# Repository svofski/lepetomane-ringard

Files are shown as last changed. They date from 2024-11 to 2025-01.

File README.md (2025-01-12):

# Pétomane ringard

A "simple" 3-voice "sound chip" with wavetables.

## Current status: 
 - [x] waiting for the first revision of PCB
 - [x] research implementation of USB MIDI
   - [ ] pico firmware in [sw/pico](sw/pico)
 - [x] audio level meter based on CH32V003
    - [CH32V003 specific notes](CH32V003-notes.md)
    - The code for the level meter is [here](wch-ch32v003/pio-arduino-ch32v003)
 - [x] assemble the PCB
   - [x] audio level meter
   - [x] Pi Pico host board
   - [x] main board
 - [ ] verification
   - [x] write a simple serial debug monitor
   - [x] 82c54 can be programmed, produces frequencies as expected
   - [x] counters U10, U11, U12 generate LSB addresses
     - this is hard to verify without a full logic probe (and even with one) but the counting period seems to be correct. I set ctr0 divider = 100, PITCHx256_A is 80kHz; pin U10.9 nRCO has short pulses at 312.5kHz, which is expected because 80e3/256 = 312.5
   - [ ] 82c55
   - [ ] MVOL DAC
   - [ ] WRMODE
   - [ ] LOOPEN_B (one-shot count on channel B)

## About this project

A never ending search of a simple chiptune synthesizer design that could have existed back in the 1980s. This design departs from the tech available to hobbyists in the 80s, but it's not too out there either. 

### Description in broad strokes

The master clock is 8MHz. Potentially 10MHz, but it would be pushing the capabilities of 82C54. The timer divides the main frequency and provides the pitch for the 3 channels. 

Waveforms are stored as samples in a ROM. This is essentially a short sample player. A sample is always 256 counts long, 8-bit waveform. For example, a sawtooth would be a sequence of numbers 0..255 stored in addresses 0..255. 
The ROM has 16 address bits, so there are 256 waveforms. This is how timbre and volume are set: simply by selecting 8 MSB of the sample address. It is possible to define just one waveshape and 256 amplitude levels, or for example 4 waveshapes and 64 amplitude levels for each one. Or several MSB bits could be reserved for selecting drum samples. It's a relatively flexible system.

One important remark. Because this is a frequency divider and the base frequency is only 8MHz, we don't get a good resolution if samples represent a single period. For decent musical resolution the waveforms will have to be squeezed to maybe 32 or 64 samples per period.

The 3 channels are time-multiplexed and sent to the two channels of DAC (TLC7258C) in a sequence. In order to provide a stereo mix, channels A/B/C/A/B/C are steered to channels L/L/R/L/R/R. Hopefully this will create an effect of a stereo mix where Left = A + 0.5B and Right = 0.5 + C.

There is a master volume which is just a second DAC providing reference voltage for the main DAC. If the main DAC is stopped, the master volume can be used to play back samples directly.

Channel B (central) can optionally stop after playing a sample once. This may be useful to play back short drum samples.

The MSB for channels A/B/C is set respectively in the registers A/B/C of 82C55. 

Because ROMs are a rare beast in 2024, K6X4008C1F SRAM is used instead. Only 64K of available address space is used. Loading is facilitated by the same 82C55 chip.

The external interface in the Pétomanesque tradition looks like a parallel port "ПУ" of Vector-06C, but in reality it's just a cursed three-row 2.54mm pin header. It is yet to be discovered whether this could ever be useful in a real computer or not. For now Raspberry Pi Pico will be used as a main driver for this board.

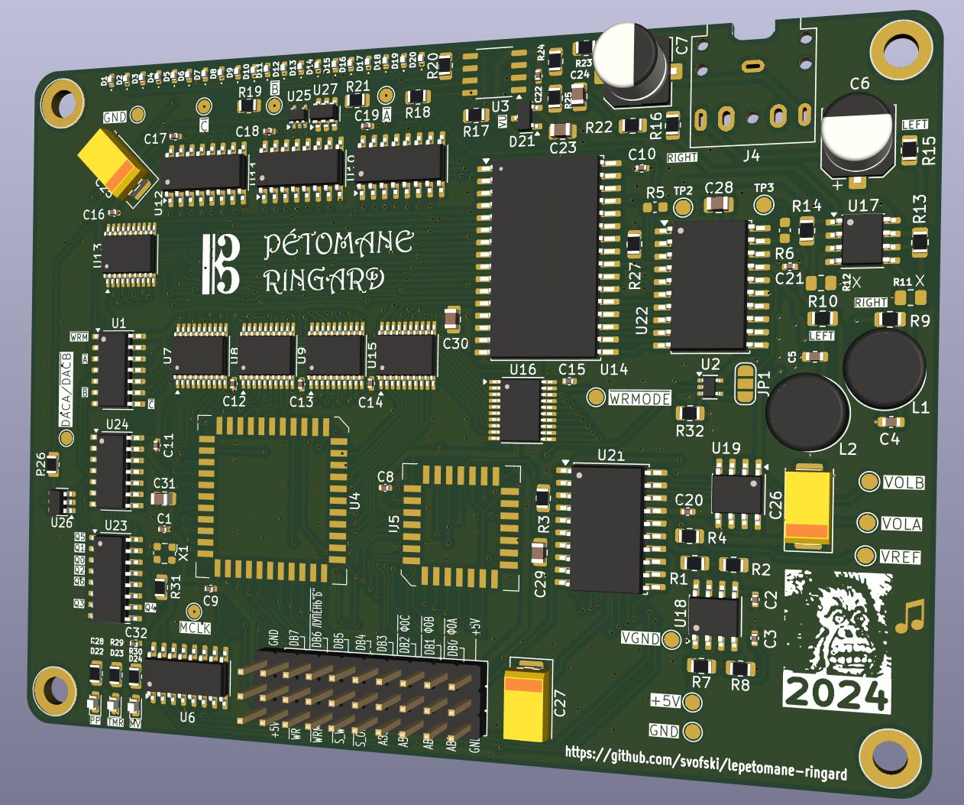
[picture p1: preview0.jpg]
preview


The complexity of this design surpasses the original expecation, yet remains within realm of possibility for a 80s design. SRAM in such quantities would have been wildly expensive back in the day, so a ROM could be used instead.

## Schematic/BOM
 * [https://github.com/svofski/lepetomane-ringard/tree/master/kicad/neopeto](https://kicanvas.org/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)
 * [ibom](https://svofski.github.io/lepetomane-ringard/ibom.html)

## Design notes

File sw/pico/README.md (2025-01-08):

# Raspberry Pi Pico Firmware

Nothing of substance here yet.

# Building

```
mkdir build && cd build && cmake ..
ninja
...
picotool load ringard.bin
```

`picotool reboot -u -f` will not work because reset interface is not implemented, however a 1200 baud hack works. 

On Windows invoke `mode com30 1200` to put pico back into bootloader mode. 

Sometimes USB device would enter some indeterminate state. Use `USBTreeView.exe` to locate the failed hub and invoke `Restart Device` on it.

# Breadcrumbs

### USB / MIDI etc

 * tinymidi example and infovore's [pico-example-midi](https://github.com/infovore/pico-example-midi)
 * Paul Fortescue's [Miscellaneous](https://github.com/PaulFortescue/Miscellaneous)
 * [MIDI as part of a Composite Device #2158](https://github.com/hathach/tinyusb/issues/2158)

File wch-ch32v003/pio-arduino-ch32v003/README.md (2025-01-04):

# Audio level meter based on CH32V003J4M6

This is a simple audio level meter based on a very cheap and compact RISC V based microcontroller. There exist dedicated chips like LM3915, but they are old designs, probably not in production anymore and they are getting harder to find. They also tend to take a lot of board space.

This is a software-defined audio level meter. The circuit is almost as simple as LM3915, but provides more flexibility in terms of functionality as well as PCB layout. The bargraph display proper consists of 20 LEDs. The MCU chip only has 6 pins available for I/O, so the LEDs are charlieplexed.

Charlieplexing is a method of driving a high number of LEDs using few legs. The downside of this method is that multiple LEDs can't be turned on at the same time. In order to display a bar graph, the multiplexing factor is high. In this case 1:20.

video

The LEDs can be grayscaled using PWM. In this application this effect is not practical so the LEDs are on/off only.

The meter is not calibrated to display any specific range of levels, the only thing I aimed for is for it to be entertaining and nice to watch. There are parameters that can be adjusted in the code, such as input gain, integration speed, decay speed and peak holding time. Only integer maths is used.

## Approximate specifications

The numbers, especially refresh rate and sampling rate are approximate just to give the general ballpark figure.

| parameter | value | remark |
| -- | -- | -- |
| supply voltage | 5V or 3.3V |
| number of LEDs | 20 |
| refresh rate | approx. 2.2kHz | 241 cycles / conversion | 
| sampling frequency | 43kHz (estimated) | 241 cycles / conversion |
| refresh rate | approx. 5.1kHz | 73 cycles / conversion |
| sampling frequency | 102kHz (estimated) | 73 cycles / conversion |
| input amplitude | 1V<sub>p-p</sub> |

The ADC is used in continuous sampling mode and the sampling rate is subject to jitter. 

ADC conversion time can be changed in platformio.ini:
```
	-DADC_CYCLES_SEL=7 ; 7: 241 cycles, 6: 73 cycles
```
There is also an artificial delay in the main loop. It has slight effect on perceived brightness and update speeds and can be adjusted to taste. 

## Schematics and layout

This is the complete schematics. There are 3 test pads used for connecting the programmer.
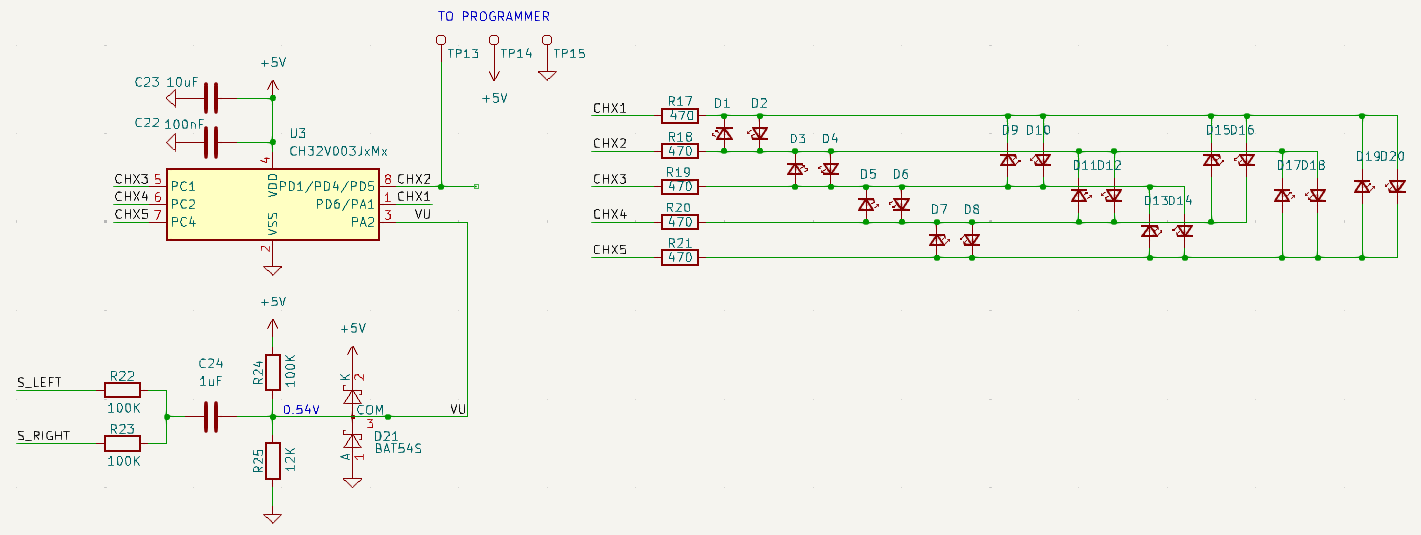
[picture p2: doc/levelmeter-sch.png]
schematics


Example layout on my PCB. Relevant parts are highlighted. The LEDs are 0402.
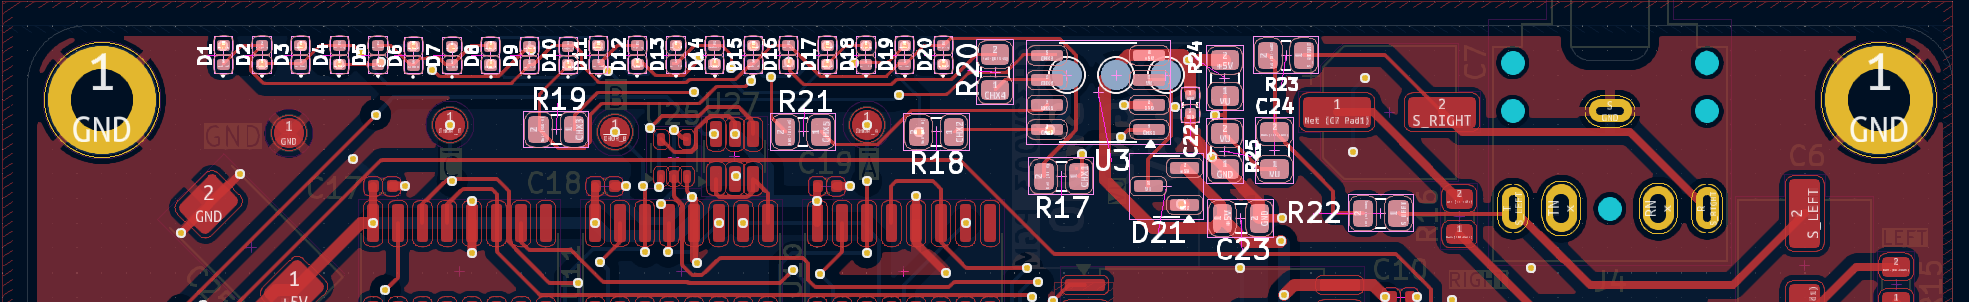
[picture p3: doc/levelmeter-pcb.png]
layout


## Building

The project builds using PlatformIO. See [CH32V003 notes](/CH32V003-notes.md) about setting up the environment.

## Things to improve

 * ADC work is crude.

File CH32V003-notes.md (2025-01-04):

# Notes about using CH32V003J4M6

## Essentials
  
 * Everywhere it's said that only WCH-LinkE will work with this micro. This could be the case in the past, but at the day of writing this (Jan 2025) this is not true. WCH-LinkW also works, even though minichlink.exe might report it as unknown programmer.
 * When the programming pin is also used as GPIO output, it may be impossible to reprogram the micro without removing it from the board.
 * To avoid finding yourself with a bricked MCU, always insert a significant delay in the initialisation code before making GPIO pin PD1/PD4/PD5/SWIO an OUTPUT.
 * It appears that the power provided by the WCH-LinkW dislikes bypass caps on my board. To unbrick a bricked MCU I have to remove it from the board and connect directly to the programmer, then it works.

## Frameworks

Before installing drivers compatible with the Arduino IDE, use the original `WCH-LinkUtility` to switch the programmer into RISCV mode. It ships in ARM mode by default. There are also other ways of switching it, they are documented elsewhere.

### Arduino IDE

The chip can be programmed from the vanilla Arduino IDE thanks to this package: https://github.com/AlexanderMandera/arduino-wch32v003 -- see installation instructions on that page.
minichlink.exe requires WinUSB drivers to be installed using Zadig. This will make WCH Utility not work anymore. You can reinstall the drivers back and forth if you need to use the official utility again.

### PlatformIO

The platform ch32v will not auto-install. It can be installed using this command. This also works on windows.
```
pio pkg install -g -p https://github.com/Community-PIO-CH32V/platform-ch32v.git
```
Check out the repo for examples. There is an Arduino framework, same as the one used in Arduino IDE as well as [CNLohr's ch32v003fun](https://github.com/cnlohr/ch32v003fun).
The main repo for ch32v003fun https://github.com/cnlohr/ch32v003fun

### Floating point

It seems to be that it's enough to specify build_flags in `platformio.ini` like so:
```
build_flags = -lgcc -lm
```
However it results in unresolved reference to `__errno` from `sqrtf` or something else. There is probably a proper way of helping this, but I solved it by defining `int __errno` in the main source file.

### Pinout
ch32v003j4m6 pinout

### References
 * [CH32V003 Datasheet](/doc/CH32V003DS0.PDF)
 * [CH32V003 Reference Manual](/doc/CH32V003RM.PDF)

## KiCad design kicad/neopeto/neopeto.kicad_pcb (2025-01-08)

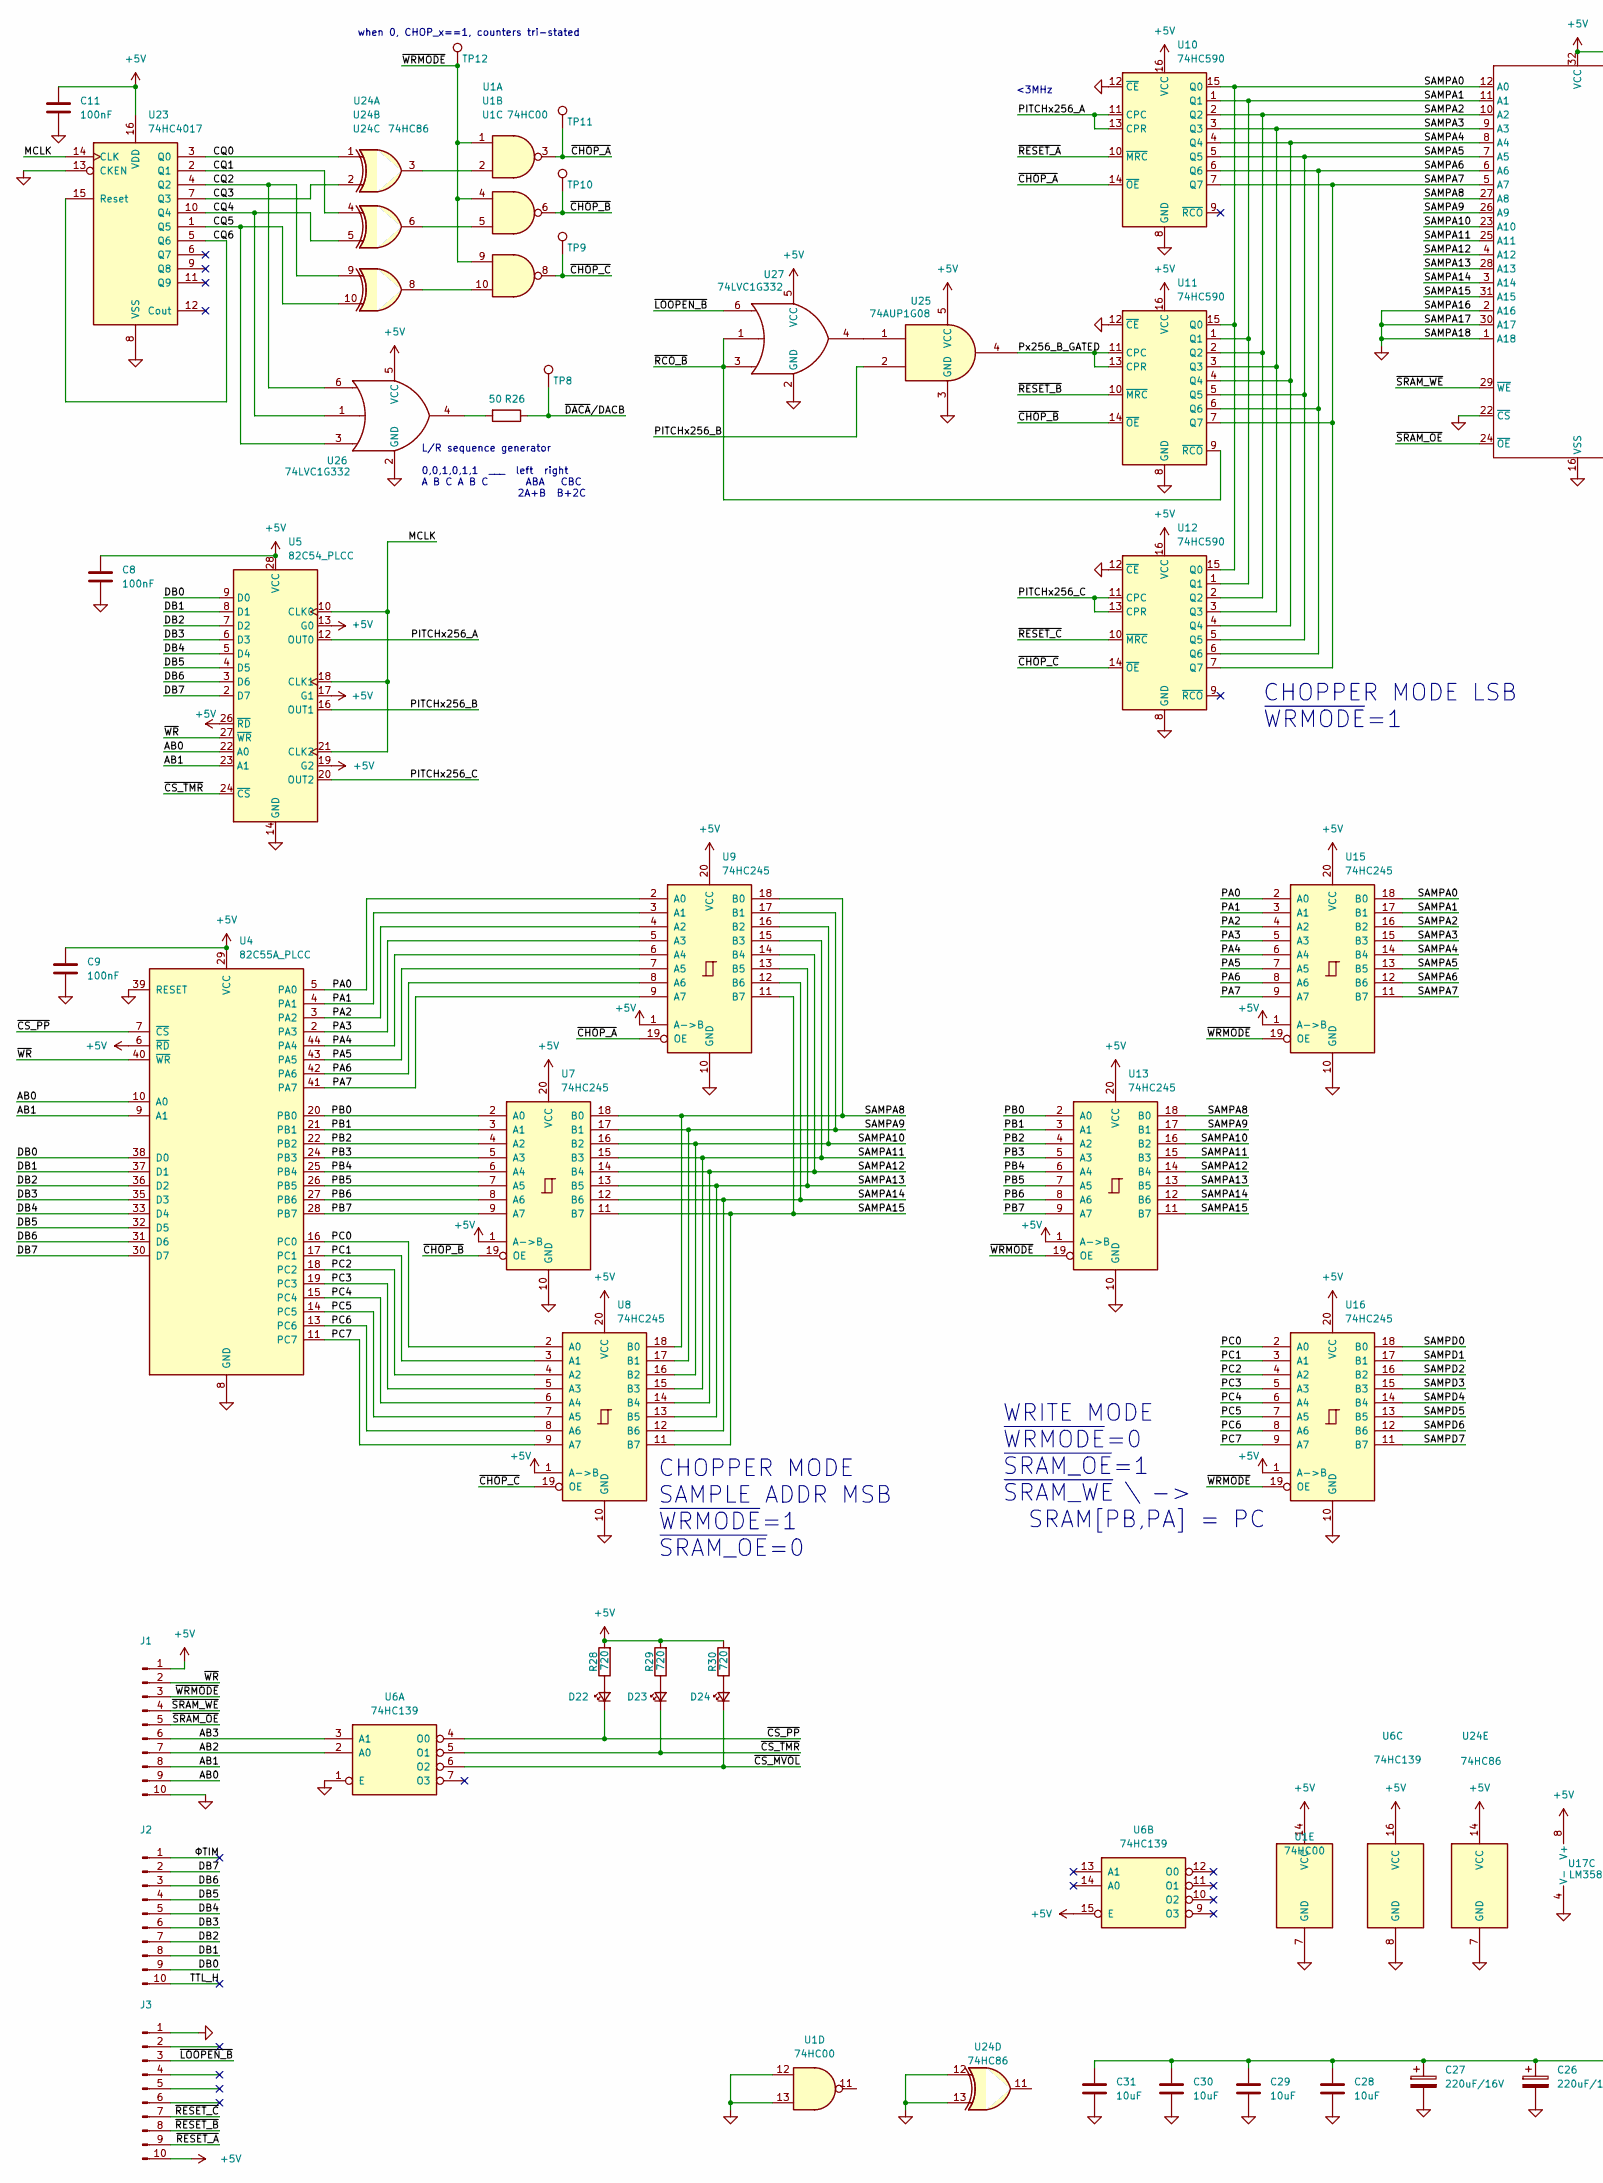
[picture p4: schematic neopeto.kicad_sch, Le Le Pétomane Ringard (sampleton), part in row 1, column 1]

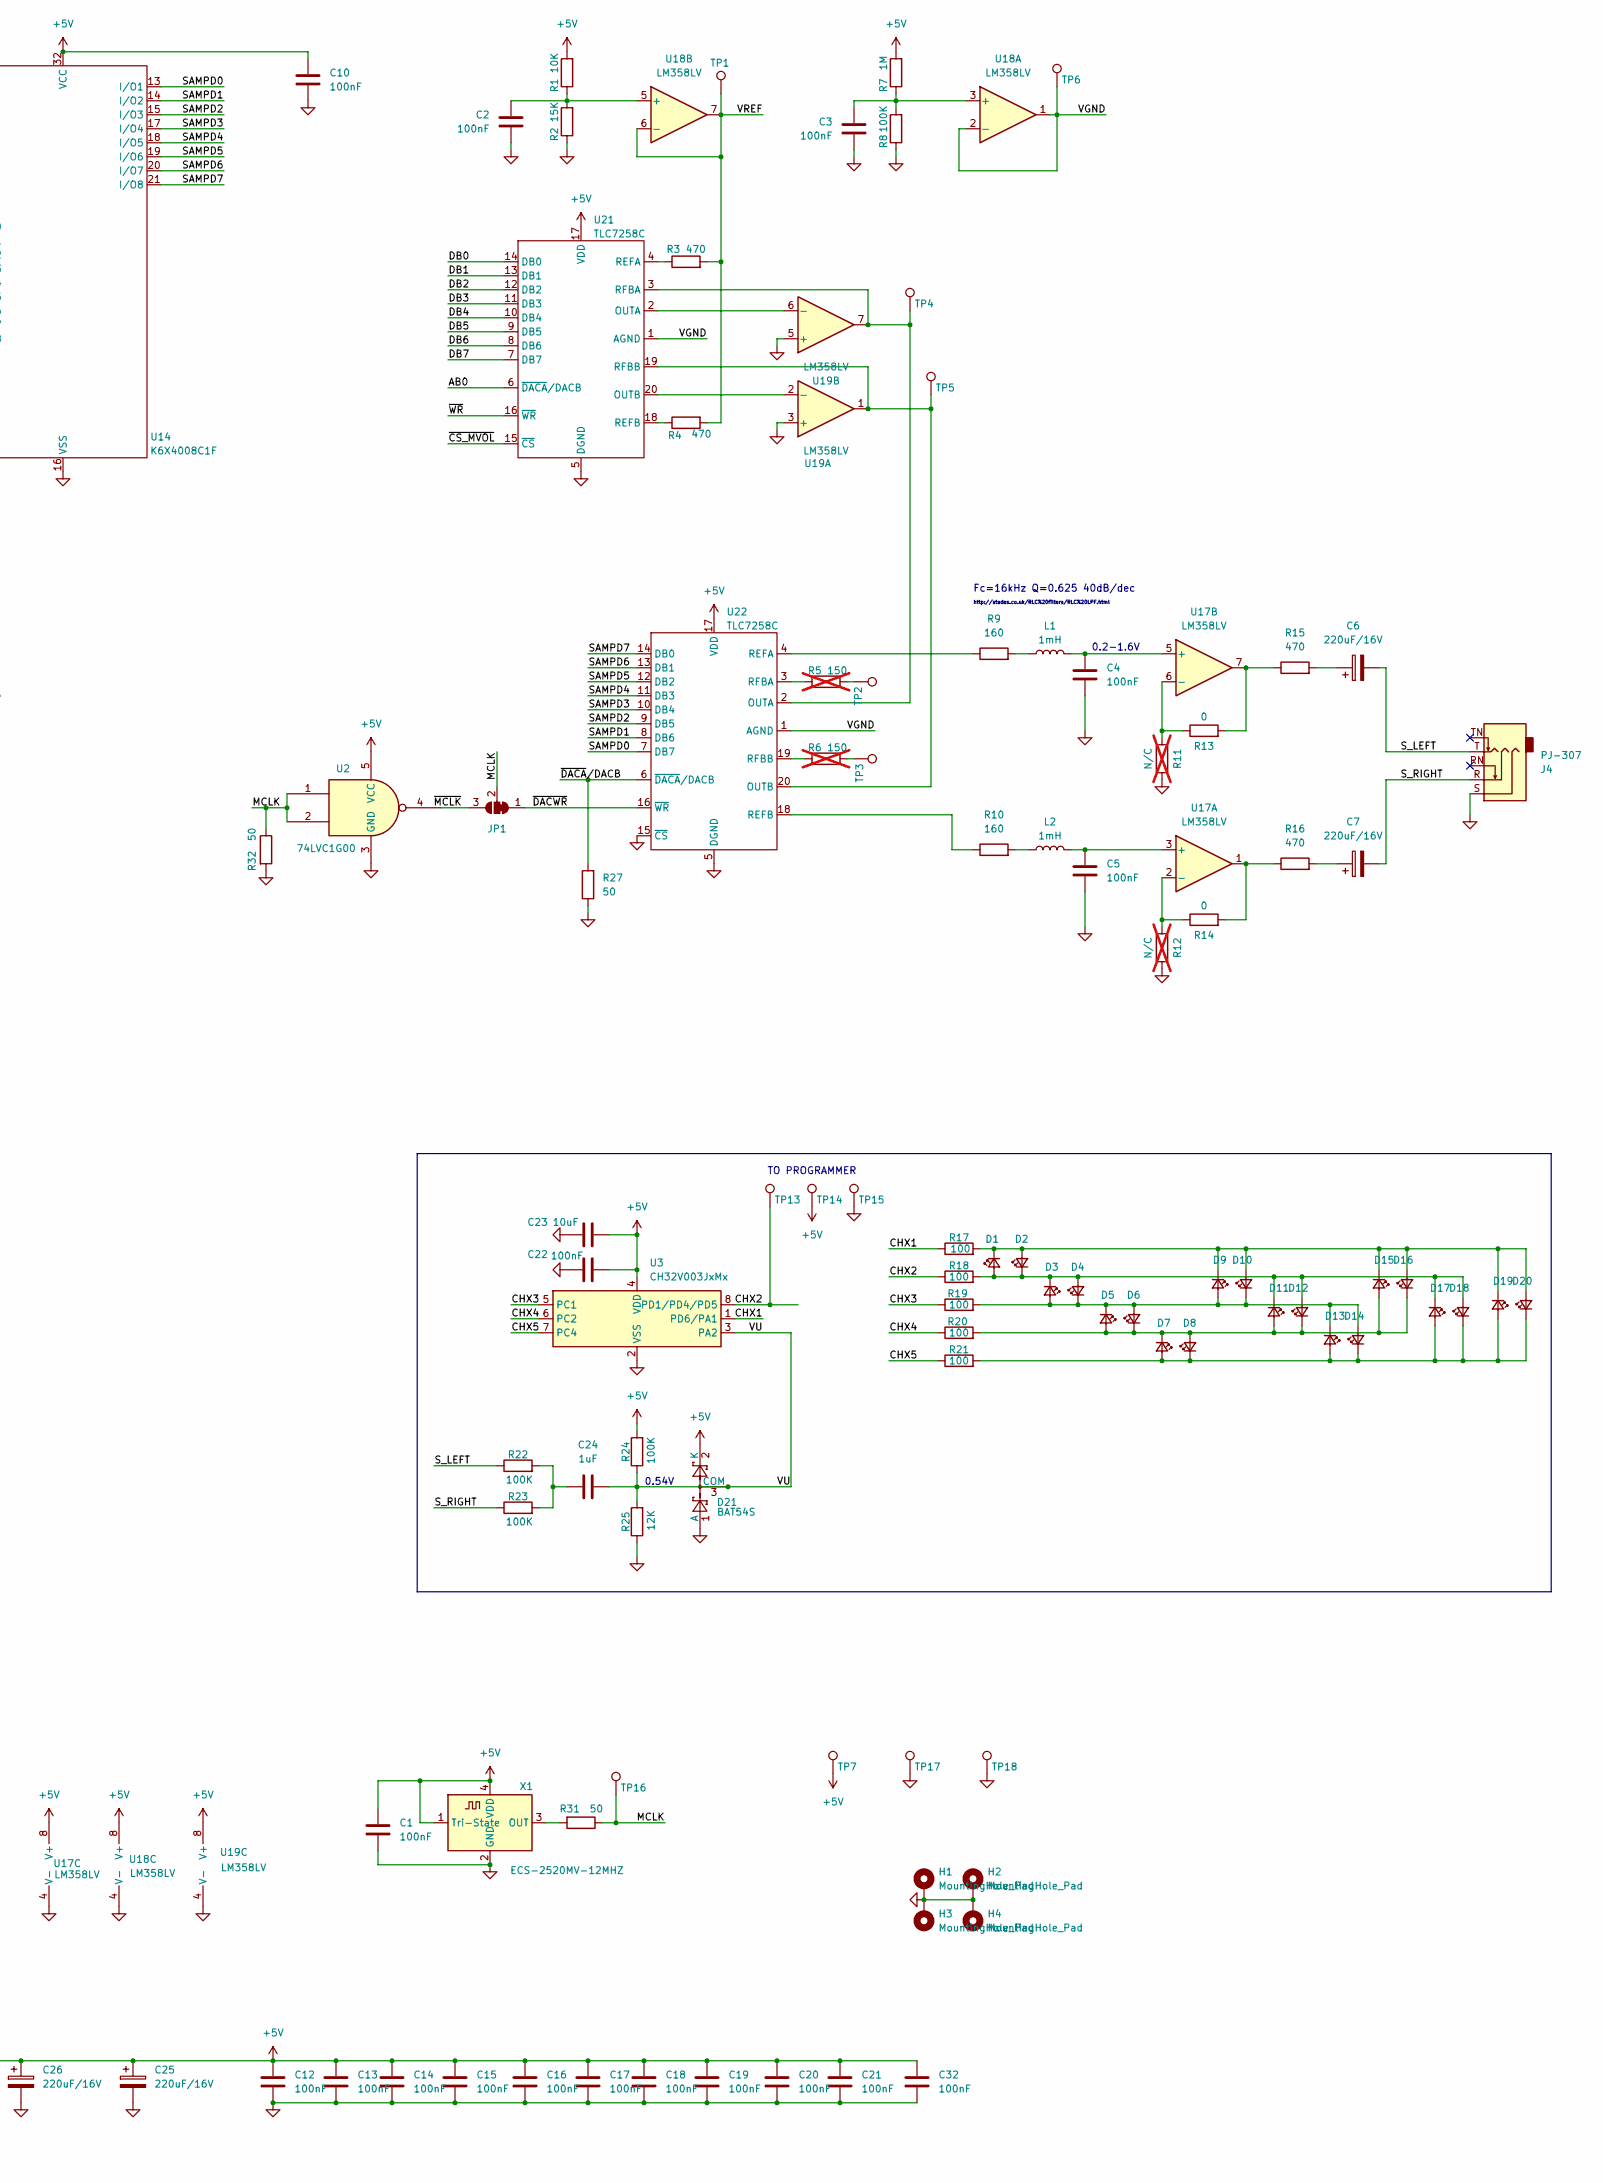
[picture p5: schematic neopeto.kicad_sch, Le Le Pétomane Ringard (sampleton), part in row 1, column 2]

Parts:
C1, C2, C3, C8, C9, C10, C11, C12, C13, C14, C15, C16, C17, C18, C19, C20, C21, C22, C32: 100nF; C_0402_1005Metric
C4, C5: 100nF; C_0603_1608Metric
C6, C7: 220uF/16V; CP_Elec_6.3x7.7
C23, C28, C29, C30, C31: 10uF; C_0805_2012Metric
C24: 1uF; C_0805_2012Metric
C25, C26, C27: 220uF/16V; CP_EIA-7343-31_Kemet-D
D1, D2, D3, D4, D5, D6, D7, D8, D9, D10, D11, D12, D13, D14, D15, D16, D17, D18, D19, D20: LED_Small; LED_0402_1005Metric
D21: BAT54S; SOT-23
D22, D23, D24: LED_Small; LED_0603_1608Metric
H1, H2, H3, H4: MountingHole_Pad; MountingHole_3.2mm_M3_DIN965_Pad
J1, J2, J3: Conn_01x10_Pin; PinHeader_1x10_P2.54mm_Vertical
J4: PJ-307; Jack_3.5mm_CUI_SJ1-3525N_Horizontal
JP1: SolderJumper_3_Bridged12; SolderJumper-3_P1.3mm_Bridged12_RoundedPad1.0x1.5mm_NumberL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
L1, L2: 1mH; L_Radial_D7.2mm_P3.00mm_Murata_1700
R1: 10K; R_0805_2012Metric
R2: 15K; R_0805_2012Metric
R3, R4, R15, R16: 470; R_0805_2012Metric
R5, R6: 150; C_0603_1608Metric; not fitted
R7: 1M; R_0805_2012Metric
R8, R22, R23, R24: 100K; R_0805_2012Metric
R9, R10: 160; R_0805_2012Metric
R11, R12: N/C; R_0805_2012Metric; not fitted
R13, R14: 0; R_0805_2012Metric
R17, R18, R19, R20, R21: 100; R_0805_2012Metric
R25: 12K; R_0805_2012Metric
R26, R27, R31, R32: 50; R_0805_2012Metric
R28, R29, R30: 720; R_0805_2012Metric
TP1, TP2, TP3, TP4, TP5, TP6, TP7, TP8, TP9, TP10, TP11, TP12, TP13, TP14, TP15, TP16, TP17, TP18: TestPoint; TestPoint_Pad_D1.5mm
U1: 74HC00; SO-14_3.9x8.65mm_P1.27mm
U2: 74LVC1G00; SOT-353_SC-70-5
U3: CH32V003JxMx; SOP-8_3.9x4.9mm_P1.27mm
U4: 82C55A_PLCC; PLCC-44
U5: 82C54_PLCC; PLCC-28
U6: 74HC139; SOIC-16_3.9x9.9mm_P1.27mm
U7, U8, U9, U13, U15, U16: 74HC245; TSSOP-20_4.4x6.5mm_P0.65mm
U10, U11, U12: 74HC590; SOIC-16_3.9x9.9mm_P1.27mm
U14: K6X4008C1F; SSOP-32_11.305x20.495mm_P1.27mm
U17, U18, U19: LM358LV; SOIC-8_3.9x4.9mm_P1.27mm
U21, U22: TLC7258C; SOIC-20W_7.5x12.8mm_P1.27mm
U23: 74HC4017; SOIC-16_3.9x9.9mm_P1.27mm
U24: 74HC86; SO-14_3.9x8.65mm_P1.27mm
U25: 74AUP1G08; SOT-353_SC-70-5
U26, U27: 74LVC1G332; SOT-23-6
X1: ECS-2520MV-12MHZ; Oscillator_SMD_ECS_2520MV-xxx-xx-4Pin_2.5x2.0mm

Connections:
+5V: C1.2, C8.2, C9.2, C10.2, C11.2, C12.2, C13.2, C14.2, C15.2, C16.2, C17.2, C18.2, C19.2, C20.2, C21.2, C22.1, C23.1, C25.1, C26.1, C27.1, C28.2, C29.2, C30.2, C31.2, C32.2, D21.2 (K), J1.1, J3.10, R1.2, R7.2, R24.2, R28.2, R29.2, R30.2, TP7.1, TP14.1, U1.14 (VCC), U2.5 (VCC), U3.4 (VDD), U4.6 (~RD), U4.29 (VCC), U5.13 (G0), U5.17 (G1), U5.19 (G2), U5.26 (~RD), U5.28 (VCC), U6.15 (E), U6.16 (VCC), U7.1 (A->B), U7.20 (VCC), U8.1 (A->B), U8.20 (VCC), U9.1 (A->B), U9.20 (VCC), U10.16 (VCC), U11.16 (VCC), U12.16 (VCC), U13.1 (A->B), U13.20 (VCC), U14.32 (VCC), U15.1 (A->B), U15.20 (VCC), U16.1 (A->B), U16.20 (VCC), U17.8 (V+), U18.8 (V+), U19.8 (V+), U21.17 (VDD), U22.17 (VDD), U23.16 (VDD), U24.14 (VCC), U25.5 (VCC), U26.5 (VCC), U27.5 (VCC), X1.1 (Tri-State), X1.4 (VDD)
/AB0: J1.9, U4.10 (A0), U5.22 (A0), U21.6 (~DACA/DACB)
/AB1: J1.8, U4.9 (A1), U5.23 (A1)
/AB2: J1.7, U6.2 (A0)
/AB3: J1.6, U6.3 (A1)
/CHX1: R17.1, U3.1 (PD6/PA1)
/CHX2: R18.1, TP13.1, U3.8 (PD1/PD4/PD5)
/CHX3: R19.1, U3.5 (PC1)
/CHX4: R20.1, U3.6 (PC2)
/CHX5: R21.1, U3.7 (PC4)
/CQ0: U23.3 (Q0), U24.1
/CQ1: U23.2 (Q1), U24.4
/CQ2: U23.4 (Q2), U24.9, U26.6
/CQ3: U23.7 (Q3), U24.2
/CQ4: U23.10 (Q4), U24.5, U26.1
/CQ5: U23.1 (Q5), U24.10, U26.3
/CQ6: U23.5 (Q6), U23.15 (Reset)
/DB0: J2.9, U4.38 (D0), U5.9 (D0), U21.14 (DB0)
/DB1: J2.8, U4.37 (D1), U5.8 (D1), U21.13 (DB1)
/DB2: J2.7, U4.36 (D2), U5.7 (D2), U21.12 (DB2)
/DB3: J2.6, U4.35 (D3), U5.6 (D3), U21.11 (DB3)
/DB4: J2.5, U4.33 (D4), U5.5 (D4), U21.10 (DB4)
/DB5: J2.4, U4.32 (D5), U5.4 (D5), U21.9 (DB5)
/DB6: J2.3, U4.31 (D6), U5.3 (D6), U21.8 (DB6)
/DB7: J2.2, U4.30 (D7), U5.2 (D7), U21.7 (DB7)
/MCLK: JP1.2 (C), R31.1, R32.1, TP16.1, U2.1, U2.2, U5.10 (CLK0), U5.18 (CLK1), U5.21 (CLK2), U23.14 (CLK)
/PA0: U4.5 (PA0), U9.2 (A0), U15.2 (A0)
/PA1: U4.4 (PA1), U9.3 (A1), U15.3 (A1)
/PA2: U4.3 (PA2), U9.4 (A2), U15.4 (A2)
/PA3: U4.2 (PA3), U9.5 (A3), U15.5 (A3)
/PA4: U4.44 (PA4), U9.6 (A4), U15.6 (A4)
/PA5: U4.43 (PA5), U9.7 (A5), U15.7 (A5)
/PA6: U4.42 (PA6), U9.8 (A6), U15.8 (A6)
/PA7: U4.41 (PA7), U9.9 (A7), U15.9 (A7)
/PB0: U4.20 (PB0), U7.2 (A0), U13.2 (A0)
/PB1: U4.21 (PB1), U7.3 (A1), U13.3 (A1)
/PB2: U4.22 (PB2), U7.4 (A2), U13.4 (A2)
/PB3: U4.24 (PB3), U7.5 (A3), U13.5 (A3)
/PB4: U4.25 (PB4), U7.6 (A4), U13.6 (A4)
/PB5: U4.26 (PB5), U7.7 (A5), U13.7 (A5)
/PB6: U4.27 (PB6), U7.8 (A6), U13.8 (A6)
/PB7: U4.28 (PB7), U7.9 (A7), U13.9 (A7)
/PC0: U4.16 (PC0), U8.2 (A0), U16.2 (A0)
/PC1: U4.17 (PC1), U8.3 (A1), U16.3 (A1)
/PC2: U4.18 (PC2), U8.4 (A2), U16.4 (A2)
/PC3: U4.19 (PC3), U8.5 (A3), U16.5 (A3)
/PC4: U4.15 (PC4), U8.6 (A4), U16.6 (A4)
/PC5: U4.14 (PC5), U8.7 (A5), U16.7 (A5)
/PC6: U4.13 (PC6), U8.8 (A6), U16.8 (A6)
/PC7: U4.11 (PC7), U8.9 (A7), U16.9 (A7)
/PITCHx256_A: U5.12 (OUT0), U10.11 (CPC), U10.13 (CPR)
/PITCHx256_B: U5.16 (OUT1), U25.2
/PITCHx256_C: U5.20 (OUT2), U12.11 (CPC), U12.13 (CPR)
/Px256_B_GATED: U11.11 (CPC), U11.13 (CPR), U25.4
/SAMPA0: U10.15 (Q0), U11.15 (Q0), U12.15 (Q0), U14.12 (A0), U15.18 (B0)
/SAMPA1: U10.1 (Q1), U11.1 (Q1), U12.1 (Q1), U14.11 (A1), U15.17 (B1)
/SAMPA2: U10.2 (Q2), U11.2 (Q2), U12.2 (Q2), U14.10 (A2), U15.16 (B2)
/SAMPA3: U10.3 (Q3), U11.3 (Q3), U12.3 (Q3), U14.9 (A3), U15.15 (B3)
/SAMPA4: U10.4 (Q4), U11.4 (Q4), U12.4 (Q4), U14.8 (A4), U15.14 (B4)
/SAMPA5: U10.5 (Q5), U11.5 (Q5), U12.5 (Q5), U14.7 (A5), U15.13 (B5)
/SAMPA6: U10.6 (Q6), U11.6 (Q6), U12.6 (Q6), U14.6 (A6), U15.12 (B6)
/SAMPA7: U10.7 (Q7), U11.7 (Q7), U12.7 (Q7), U14.5 (A7), U15.11 (B7)
/SAMPA8: U7.18 (B0), U8.18 (B0), U9.18 (B0), U13.18 (B0), U14.27 (A8)
/SAMPA9: U7.17 (B1), U8.17 (B1), U9.17 (B1), U13.17 (B1), U14.26 (A9)
/SAMPA10: U7.16 (B2), U8.16 (B2), U9.16 (B2), U13.16 (B2), U14.23 (A10)
/SAMPA11: U7.15 (B3), U8.15 (B3), U9.15 (B3), U13.15 (B3), U14.25 (A11)
/SAMPA12: U7.14 (B4), U8.14 (B4), U9.14 (B4), U13.14 (B4), U14.4 (A12)
/SAMPA13: U7.13 (B5), U8.13 (B5), U9.13 (B5), U13.13 (B5), U14.28 (A13)
/SAMPA14: U7.12 (B6), U8.12 (B6), U9.12 (B6), U13.12 (B6), U14.3 (A14)
/SAMPA15: U7.11 (B7), U8.11 (B7), U9.11 (B7), U13.11 (B7), U14.31 (A15)
/SAMPD0: U14.13 (I/O1), U16.18 (B0), U22.7 (DB7)
/SAMPD1: U14.14 (I/O2), U16.17 (B1), U22.8 (DB6)
/SAMPD2: U14.15 (I/O3), U16.16 (B2), U22.9 (DB5)
/SAMPD3: U14.17 (I/O4), U16.15 (B3), U22.10 (DB4)
/SAMPD4: U14.18 (I/O5), U16.14 (B4), U22.11 (DB3)
/SAMPD5: U14.19 (I/O6), U16.13 (B5), U22.12 (DB2)
/SAMPD6: U14.20 (I/O7), U16.12 (B6), U22.13 (DB1)
/SAMPD7: U14.21 (I/O8), U16.11 (B7), U22.14 (DB0)
/S_LEFT: C6.2, J4.T, R22.1
/S_RIGHT: C7.2, J4.R, R23.1
/TTL_H: J2.10
/VGND: TP6.1, U18.1, U18.2 (-), U21.1 (AGND), U22.1 (AGND)
/VREF: R3.2, R4.2, TP1.1, U18.6 (-), U18.7
/VU: C24.1, D21.3 (COM), R24.1, R25.2, U3.3 (PA2)
/~CHOP_A: TP11.1, U1.3, U9.19 (OE), U10.14 (~OE)
/~CHOP_B: TP10.1, U1.6, U7.19 (OE), U11.14 (~OE)
/~CHOP_C: TP9.1, U1.8, U8.19 (OE), U12.14 (~OE)
/~CS_MVOL: D24.1 (K), U6.6 (O2), U21.15 (~CS)
/~CS_PP: D22.1 (K), U4.7 (~CS), U6.4 (O0)
/~CS_TMR: D23.1 (K), U5.24 (~CS), U6.5 (O1)
/~DACA/DACB: R26.1, R27.2, TP8.1, U22.6 (~DACA/DACB)
/~DACWR: JP1.1 (A), U22.16 (~WR)
/~LOOPEN_B: J3.3, U27.6
/~MCLK: JP1.3 (B), U2.4
/~RCO_B: U11.9 (~RCO), U27.1, U27.3
/~RESET_A: J3.9, U10.10 (~MRC)
/~RESET_B: J3.8, U11.10 (~MRC)
/~RESET_C: J3.7, U12.10 (~MRC)
/~SRAM_OE: J1.5, U14.24 (~OE)
/~SRAM_WE: J1.4, U14.29 (~WE)
/~WRMODE: J1.3, TP12.1, U1.1, U1.4, U1.9, U13.19 (OE), U15.19 (OE), U16.19 (OE)
/~WR: J1.2, U4.40 (~WR), U5.27 (~WR), U21.16 (~WR)
/ФTIM: J2.1
GND: C1.1, C2.1, C3.1, C4.1, C5.1, C8.1, C9.1, C10.1, C11.1, C12.1, C13.1, C14.1, C15.1, C16.1, C17.1, C18.1, C19.1, C20.1, C21.1, C22.2, C23.2, C25.2, C26.2, C27.2, C28.1, C29.1, C30.1, C31.1, C32.1, D21.1 (A), H1.1, H2.1, H3.1, H4.1, J1.10, J3.1, J4.S, R2.1, R8.1, R11.1, R12.1, R25.1, R27.1, R32.2, TP15.1, TP17.1, TP18.1, U1.7 (GND), U1.12, U1.13, U2.3 (GND), U3.2 (VSS), U4.8 (GND), U4.39 (RESET), U5.14 (GND), U6.1 (E), U6.8 (GND), U7.10 (GND), U8.10 (GND), U9.10 (GND), U10.8 (GND), U10.12 (~CE), U11.8 (GND), U11.12 (~CE), U12.8 (GND), U12.12 (~CE), U13.10 (GND), U14.1 (A18), U14.2 (A16), U14.16 (VSS), U14.22 (~CS), U14.30 (A17), U15.10 (GND), U16.10 (GND), U17.4 (V-), U18.4 (V-), U19.3 (+), U19.4 (V-), U19.5 (+), U21.5 (DGND), U22.5 (DGND), U22.15 (~CS), U23.8 (VSS), U23.13 (CKEN), U24.7 (GND), U24.12, U24.13, U25.3 (GND), U26.2 (GND), U27.2 (GND), X1.2 (GND)
unnamed: C6.1, R15.2
unnamed: C7.1, R16.2
unnamed: C24.2, R22.2, R23.2
unnamed: D1.2 (A), D2.1 (K), D3.1 (K), D4.2 (A), D11.1 (K), D12.2 (A), D17.1 (K), D18.2 (A), R18.2
unnamed: D1.1 (K), D2.2 (A), D9.1 (K), D10.2 (A), D15.1 (K), D16.2 (A), D19.1 (K), D20.2 (A), R17.2
unnamed: D3.2 (A), D4.1 (K), D5.1 (K), D6.2 (A), D9.2 (A), D10.1 (K), D13.1 (K), D14.2 (A), R19.2
unnamed: D5.2 (A), D6.1 (K), D7.1 (K), D8.2 (A), D11.2 (A), D12.1 (K), D15.2 (A), D16.1 (K), R20.2
unnamed: D7.2 (A), D8.1 (K), D13.2 (A), D14.1 (K), D17.2 (A), D18.1 (K), D19.2 (A), D20.1 (K), R21.2
unnamed: D22.2 (A), R28.1
unnamed: D23.2 (A), R29.1
unnamed: D24.2 (A), R30.1
unnamed: L1.1, R9.2
unnamed: L2.1, R10.2
unnamed: R5.2, TP2.1
unnamed: R6.2, TP3.1
unnamed: R13.2, R15.1, U17.7
unnamed: R14.2, R16.1, U17.1
unnamed: R26.2, U26.4
unnamed: U1.2, U24.3
unnamed: U1.5, U24.6
unnamed: U1.10, U24.8
unnamed: C5.2, L2.2, U17.3 (+)
unnamed: R12.2, R14.1, U17.2 (-)
unnamed: C4.2, L1.2, U17.5 (+)
unnamed: R11.2, R13.1, U17.6 (-)
unnamed: C3.2, R7.1, R8.2, U18.3 (+)
unnamed: C2.2, R1.1, R2.2, U18.5 (+)
unnamed: U19.2 (-), U21.20 (OUTB)
unnamed: U19.6 (-), U21.2 (OUTA)
unnamed: R3.1, U21.4 (REFA)
unnamed: R4.1, U21.18 (REFB)
unnamed: TP4.1, U19.7, U21.3 (RFBA), U22.2 (OUTA)
unnamed: TP5.1, U19.1, U21.19 (RFBB), U22.20 (OUTB)
unnamed: R9.1, U22.4 (REFA)
unnamed: R10.1, U22.18 (REFB)
unnamed: R5.1, U22.3 (RFBA)
unnamed: R6.1, U22.19 (RFBB)
unnamed: U25.1, U27.4
unnamed: R31.2, X1.3 (OUT)

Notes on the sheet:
CHOPPER MODE SAMPLE ADDR MSB ~{WRMODE}=1 ~{SRAM_OE}=0
http://stades.co.uk/RLC%20filters/RLC%20LPF.html
L/R sequence generator 0,0,1,0,1,1 ___ left right A B C A B C ABA CBC 2A+B B+2C
WRITE MODE ~{WRMODE}=0 ~{SRAM_OE}=1 ~{SRAM_WE} \ -> SRAM[PB,PA] = PC
<3MHz
TO PROGRAMMER
when 0, CHOP_x==1, counters tri-stated
CHOPPER MODE LSB ~{WRMODE}=1
0.2-1.6V
0.54V
Fc=16kHz Q=0.625 40dB/dec

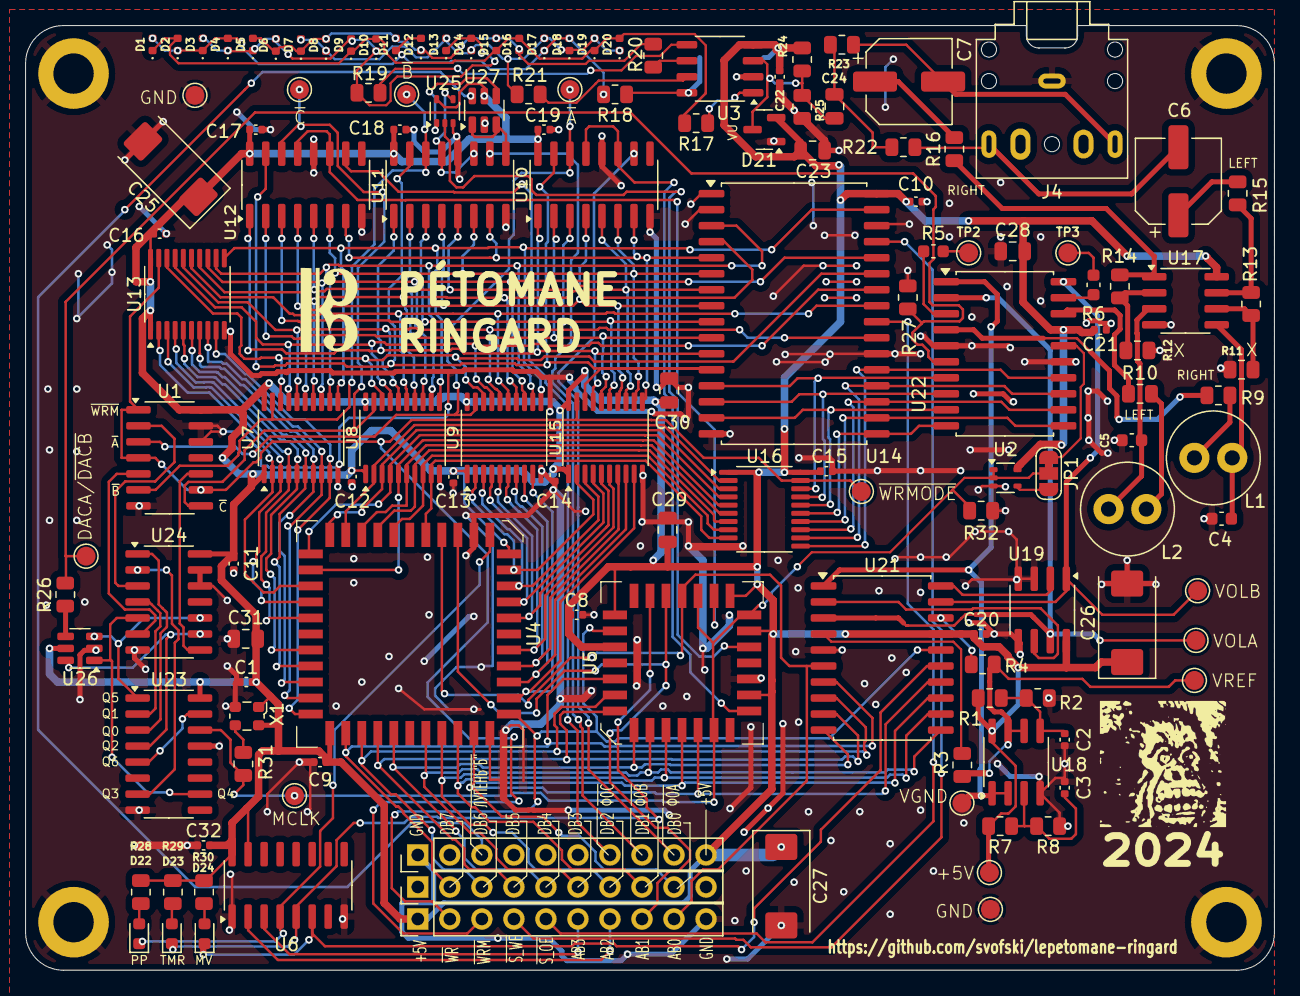
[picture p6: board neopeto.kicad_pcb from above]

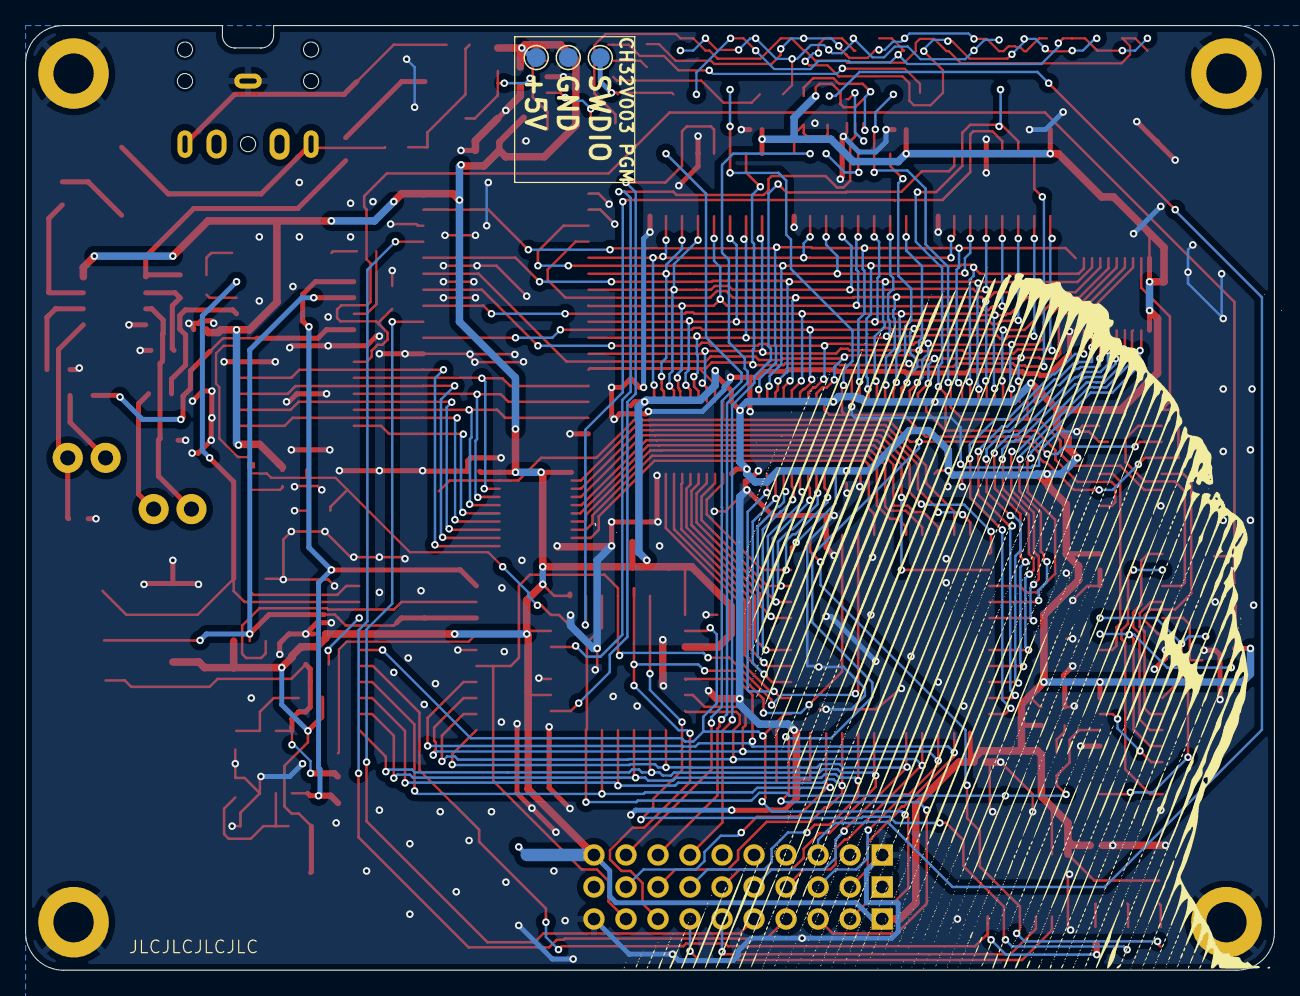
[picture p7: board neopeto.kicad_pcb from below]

Board: 2 copper layers, 99.1 x 74.9 mm, 144 parts (3 on the bottom side), 141 nets.

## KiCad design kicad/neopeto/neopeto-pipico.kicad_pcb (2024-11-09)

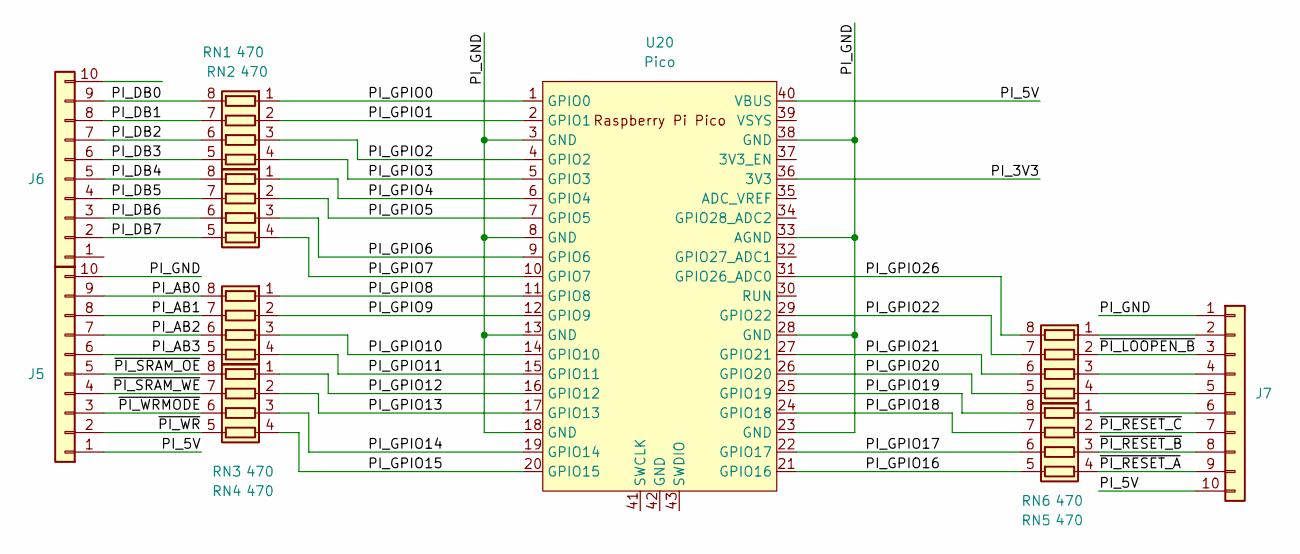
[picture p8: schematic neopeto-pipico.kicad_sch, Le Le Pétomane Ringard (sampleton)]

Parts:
J5, J6, J7: Conn_01x10; PinHeader_1x10_P2.54mm_Vertical
RN1, RN2, RN3, RN4, RN5, RN6: 470; R_Array_Concave_4x0603
U20: Pico; RPi_Pico_SMD_TH

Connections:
/PI_3V3: U20.36 (3V3)
/PI_5V: J5.1, J7.10, U20.40 (VBUS)
/PI_AB0: J5.9, RN3.8 (R1.2)
/PI_AB1: J5.8, RN3.7 (R2.2)
/PI_AB2: J5.7, RN3.6 (R3.2)
/PI_AB3: J5.6, RN3.5 (R4.2)
/PI_DB0: J6.9, RN1.8 (R1.2)
/PI_DB1: J6.8, RN1.7 (R2.2)
/PI_DB2: J6.7, RN1.6 (R3.2)
/PI_DB3: J6.6, RN1.5 (R4.2)
/PI_DB4: J6.5, RN2.8 (R1.2)
/PI_DB5: J6.4, RN2.7 (R2.2)
/PI_DB6: J6.3, RN2.6 (R3.2)
/PI_DB7: J6.2, RN2.5 (R4.2)
/PI_GND: J5.10, J7.1, U20.3 (GND), U20.8 (GND), U20.13 (GND), U20.18 (GND), U20.23 (GND), U20.28 (GND), U20.33 (AGND), U20.38 (GND)
/PI_GPIO0: RN1.1 (R1.1), U20.1 (GPIO0)
/PI_GPIO1: RN1.2 (R2.1), U20.2 (GPIO1)
/PI_GPIO2: RN1.3 (R3.1), U20.4 (GPIO2)
/PI_GPIO3: RN1.4 (R4.1), U20.5 (GPIO3)
/PI_GPIO4: RN2.1 (R1.1), U20.6 (GPIO4)
/PI_GPIO5: RN2.2 (R2.1), U20.7 (GPIO5)
/PI_GPIO6: RN2.3 (R3.1), U20.9 (GPIO6)
/PI_GPIO7: RN2.4 (R4.1), U20.10 (GPIO7)
/PI_GPIO8: RN3.1 (R1.1), U20.11 (GPIO8)
/PI_GPIO9: RN3.2 (R2.1), U20.12 (GPIO9)
/PI_GPIO10: RN3.3 (R3.1), U20.14 (GPIO10)
/PI_GPIO11: RN3.4 (R4.1), U20.15 (GPIO11)
/PI_GPIO12: RN4.1 (R1.1), U20.16 (GPIO12)
/PI_GPIO13: RN4.2 (R2.1), U20.17 (GPIO13)
/PI_GPIO14: RN4.3 (R3.1), U20.19 (GPIO14)
/PI_GPIO15: RN4.4 (R4.1), U20.20 (GPIO15)
/PI_GPIO16: RN5.5 (R4.2), U20.21 (GPIO16)
/PI_GPIO17: RN5.6 (R3.2), U20.22 (GPIO17)
/PI_GPIO18: RN5.7 (R2.2), U20.24 (GPIO18)
/PI_GPIO19: RN5.8 (R1.2), U20.25 (GPIO19)
/PI_GPIO20: RN6.5 (R4.2), U20.26 (GPIO20)
/PI_GPIO21: RN6.6 (R3.2), U20.27 (GPIO21)
/PI_GPIO22: RN6.7 (R2.2), U20.29 (GPIO22)
/PI_GPIO26: RN6.8 (R1.2), U20.31 (GPIO26_ADC0)
/~PI_LOOPEN_B: J7.3, RN6.2 (R2.1)
/~PI_RESET_A: J7.9, RN5.4 (R4.1)
/~PI_RESET_B: J7.8, RN5.3 (R3.1)
/~PI_RESET_C: J7.7, RN5.2 (R2.1)
/~PI_SRAM_OE: J5.5, RN4.8 (R1.2)
/~PI_SRAM_WE: J5.4, RN4.7 (R2.2)
/~PI_WRMODE: J5.3, RN4.6 (R3.2)
/~PI_WR: J5.2, RN4.5 (R4.2)
unnamed: J7.2, RN6.1 (R1.1)
unnamed: J7.4, RN6.3 (R3.1)
unnamed: J7.5, RN6.4 (R4.1)
unnamed: J7.6, RN5.1 (R1.1)

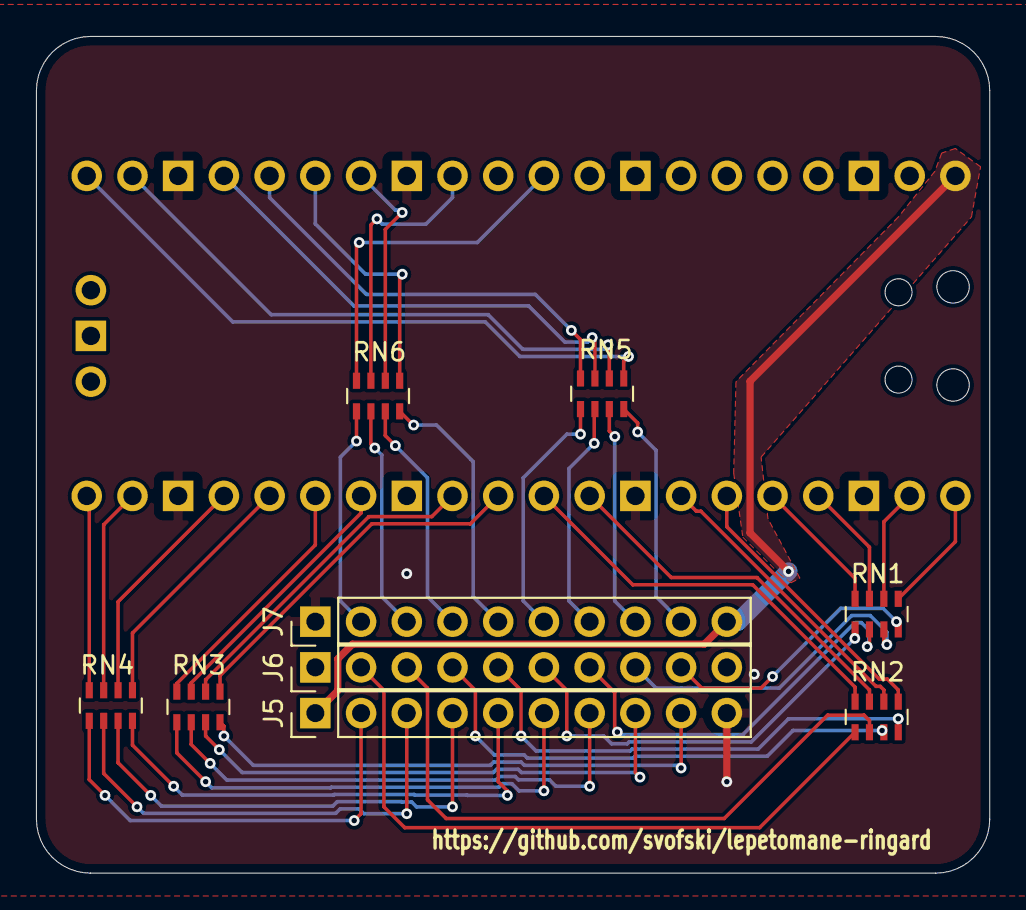
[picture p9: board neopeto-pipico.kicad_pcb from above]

Board: 2 copper layers, 53.0 x 46.5 mm, 10 parts (1 on the bottom side), 50 nets.

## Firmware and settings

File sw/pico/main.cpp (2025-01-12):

#include <array>
#include <cstdlib>

#include <stdio.h>
#include "pico/stdlib.h"
#include "hardware/gpio.h"
#include "pico/binary_info.h"

#include "bsp/board.h"
#include "tusb.h"

#include "petomane.h"

enum  {
    BLINK_NOT_MOUNTED = 250,
    BLINK_MOUNTED = 1000,
    BLINK_SUSPENDED = 2500,
};

Petomane petomane;

static uint32_t blink_interval_ms = BLINK_NOT_MOUNTED;
const uint LED_PIN = PICO_DEFAULT_LED_PIN;

void led_blinking_task(void);
void midi_task(void);

struct DebugMonitor
{
    Petomane& petomane;
    std::array<char, 64> cmdbuf;
    int bufindex;
    int wrn = 0;

    DebugMonitor(Petomane& p): petomane(p), bufindex(0) {}

    void task()
    {
        int c = getchar_timeout_us(10);
        if (c >= 0 && c <= 255) {
            if (c == '\r') {
                c = '\n';
            }
            putchar(c);
            if (c == '\n' || bufindex >= cmdbuf.size() - 1) {
                c = 0;
            }
            cmdbuf[bufindex++] = c;
            if (c == 0) {
                if (bufindex > 1) {
                    process_cmd();
                }
                bufindex = 0;
            }
        }
    }

    void process_cmd()
    {
        int result = 0;
        switch (cmdbuf[0]) {
            case 'd':
                result = process_div();
                break;
            case 'b':
                result = process_bus();
                break;
            case 'w':
                gpio_put(15, wrn);
                wrn ^= 1;
                break;
            default:
                printf("unknown command: [%s]\n", &cmdbuf[0]);
                break;
        }

        if (result == 0) {
            printf("OK\n");
        }
        else {
            printf("ERROR\n");
        }
    }

    void skip_whitespace(int& pos)
    {
        while ((cmdbuf[pos] == ' ' || cmdbuf[pos] == '\t') && pos < cmdbuf.size()) ++pos;
    }

    // d 0 1234 -- sets chan 0 divider to 1234 decimal
    int process_div()
    {
        int pos = 1;

        // first arg
        skip_whitespace(pos);
        if (pos >= cmdbuf.size()) return -1;
        int chan = cmdbuf[pos] - '0';
        if (chan < 0 || chan > 2) return -1;

        // second arg
        ++pos; 
        skip_whitespace(pos);
        if (pos >= cmdbuf.size()) return -1;

        int div = atoi(&cmdbuf[pos]);
        if (div < 0 || div > 65535) return -1;

        printf("set div[%d]=%d\n", chan, div);
        petomane.set_enabled(chan, true);
        petomane.set_div(chan, div);

        return 0;
    }

    // set bus
    // b a b -- abus = a, dbus = b
    // 0-3 = PPI
    // 4-7 = TIMER
    // 8-9 = MVOL
    int process_bus()
    {
        int pos = 1;

        // first arg
        skip_whitespace(pos);
        if (pos >= cmdbuf.size()) return -1;
        int a = cmdbuf[pos] - '0';
        if (a < 0 || a > 9) return -1;

        // second arg
        ++pos; 
        skip_whitespace(pos);
        if (pos >= cmdbuf.size()) return -1;

        uint8_t dbus = atoi(&cmdbuf[pos]) & 0xff;

        int dev = (a & 0xc) >> 2;
        int reg = a & 3;
        printf("set bus dev=%d reg=%d D=%02x\n", dev, reg, dbus);
        petomane.bsr_dev(dev, reg, 0, dbus);

        return 0;
    }
};

DebugMonitor debug_monitor(petomane);

int main() {
    board_init();
    stdio_init_all();
    petomane.board_init();

    tud_init(BOARD_TUD_RHPORT);

    printf("lepetomane-ringard\n");

    while (1)
    {
        tud_task(); // tinyusb device task
        led_blinking_task();
        //midi_task();
        debug_monitor.task();
    }
}

//--------------------------------------------------------------------+
// Device callbacks
//--------------------------------------------------------------------+

// Invoked when device is mounted
void tud_mount_cb(void)
{
    blink_interval_ms = BLINK_MOUNTED;
}

// Invoked when device is unmounted
void tud_umount_cb(void)
{
    blink_interval_ms = BLINK_NOT_MOUNTED;
}

// Invoked when usb bus is suspended
// remote_wakeup_en : if host allow us  to perform remote wakeup
// Within 7ms, device must draw an average of current less than 2.5 mA from bus
void tud_suspend_cb(bool remote_wakeup_en)
{
    (void) remote_wakeup_en;
    blink_interval_ms = BLINK_SUSPENDED;
}

// Invoked when usb bus is resumed
void tud_resume_cb(void)
{
    blink_interval_ms = BLINK_MOUNTED;
}

//--------------------------------------------------------------------+
// MIDI Task
//--------------------------------------------------------------------+

// Variable that holds the current position in the sequence.
uint32_t note_pos = 0;

// Store example melody as an array of note values
uint8_t note_sequence[] =
{
    74,78,81,86,90,93,98,102,57,61,66,69,73,78,81,85,88,92,97,100,97,92,88,85,81,78,
    74,69,66,62,57,62,66,69,74,78,81,86,90,93,97,102,97,93,90,85,81,78,73,68,64,61,
    56,61,64,68,74,78,81,86,90,93,98,102
};

void midi_task(void)
{
    static uint32_t start_ms = 0;
    uint8_t msg[3];

    // send note every 1000 ms
    if (board_millis() - start_ms < 286) return; // not enough time
    start_ms += 286;

    // Previous positions in the note sequence.
    int previous = note_pos - 1;

    // If we currently are at position 0, set the
    // previous position to the last note in the sequence.
    if (previous < 0) previous = sizeof(note_sequence) - 1;

    // Send Note On for current position at full velocity (127) on channel 1.
    msg[0] = 0x90;                    // Note On - Channel 1
    msg[1] = note_sequence[note_pos]; // Note Number
    msg[2] = 127;                     // Velocity
    tud_midi_n_stream_write(0, 0, msg, 3);

    printf("note_on: %02x %02x %02x\n", msg[0], msg[1], msg[2]);

    // Send Note Off for previous note.
    msg[0] = 0x80;                    // Note Off - Channel 1
    msg[1] = note_sequence[previous]; // Note Number
    msg[2] = 0;                       // Velocity
    tud_midi_n_stream_write(0, 0, msg, 3);

    // Increment position
    note_pos++;

    // If we are at the end of the sequence, start over.
    if (note_pos >= sizeof(note_sequence)) note_pos = 0;
}

//--------------------------------------------------------------------+
// BLINKING TASK
//--------------------------------------------------------------------+
void led_blinking_task(void)
{
    static uint32_t start_ms = 0;
    static bool led_state = false;

    // Blink every interval ms
    if ( board_millis() - start_ms < blink_interval_ms) return; // not enough time
    start_ms += blink_interval_ms;

    board_led_write(led_state);
    led_state = 1 - led_state; // toggle
}

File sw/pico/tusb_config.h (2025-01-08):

/*
 * The MIT License (MIT)
 *
 * Copyright (c) 2019 Ha Thach (tinyusb.org)
 *
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
 */

#ifndef _TUSB_CONFIG_H_
#define _TUSB_CONFIG_H_

#ifdef __cplusplus
 extern "C" {
#endif

//--------------------------------------------------------------------+
// Board Specific Configuration
//--------------------------------------------------------------------+

// RHPort number used for device can be defined by board.mk, default to port 0
#ifndef BOARD_TUD_RHPORT
#define BOARD_TUD_RHPORT      0
#endif

// RHPort max operational speed can defined by board.mk
#ifndef BOARD_TUD_MAX_SPEED
#define BOARD_TUD_MAX_SPEED   OPT_MODE_DEFAULT_SPEED
#endif

//--------------------------------------------------------------------
// Common Configuration
//--------------------------------------------------------------------

// defined by compiler flags for flexibility
#ifndef CFG_TUSB_MCU
#error CFG_TUSB_MCU must be defined
#endif

#define CFG_TUSB_RHPORT0_MODE     OPT_MODE_DEVICE

#ifndef CFG_TUSB_OS
#define CFG_TUSB_OS           OPT_OS_NONE
#endif

#ifndef CFG_TUSB_DEBUG
#define CFG_TUSB_DEBUG        0
#endif

// Enable Device stack
#define CFG_TUD_ENABLED       1

// Default is max speed that hardware controller could support with on-chip PHY
#define CFG_TUD_MAX_SPEED     BOARD_TUD_MAX_SPEED

/* USB DMA on some MCUs can only access a specific SRAM region with restriction on alignment.
 * Tinyusb use follows macros to declare transferring memory so that they can be put
 * into those specific section.
 * e.g
 * - CFG_TUSB_MEM SECTION : __attribute__ (( section(".usb_ram") ))
 * - CFG_TUSB_MEM_ALIGN   : __attribute__ ((aligned(4)))
 */
#ifndef CFG_TUSB_MEM_SECTION
#define CFG_TUSB_MEM_SECTION
#endif

#ifndef CFG_TUSB_MEM_ALIGN
#define CFG_TUSB_MEM_ALIGN    __attribute__ ((aligned(4)))
#endif

//--------------------------------------------------------------------
// DEVICE CONFIGURATION
//--------------------------------------------------------------------

#ifndef CFG_TUD_ENDPOINT0_SIZE
#define CFG_TUD_ENDPOINT0_SIZE    64
#endif

//------------- CLASS -------------//
#define CFG_TUD_CDC              1
#define CFG_TUD_MSC              0
#define CFG_TUD_HID              0
#define CFG_TUD_MIDI             1
#define CFG_TUD_VENDOR           0

#define CFG_TUD_MIDI_RX_BUFSIZE   (TUD_OPT_HIGH_SPEED ? 512 : 64)
#define CFG_TUD_MIDI_TX_BUFSIZE   (TUD_OPT_HIGH_SPEED ? 512 : 64)

// CDC FIFO size of TX and RX
#define CFG_TUD_CDC_RX_BUFSIZE   (TUD_OPT_HIGH_SPEED ? 512 : 64)
#define CFG_TUD_CDC_TX_BUFSIZE   (TUD_OPT_HIGH_SPEED ? 512 : 64)

// CDC Endpoint transfer buffer size, more is faster
#define CFG_TUD_CDC_EP_BUFSIZE   (TUD_OPT_HIGH_SPEED ? 512 : 64)

// MSC Buffer size of Device Mass storage
#define CFG_TUD_MSC_EP_BUFSIZE   512

#ifdef __cplusplus
 }
#endif

#endif /* _TUSB_CONFIG_H_ */

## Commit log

2024-11-02 frist commit
    [neopeto.kicad_pcb, neopeto.kicad_sch]
2024-11-08 before separation
    [neopeto.kicad_pcb, neopeto.kicad_sch]
2024-11-09 as ordered
    [neopeto.kicad_pcb, neopeto.kicad_sch]
2024-11-09 pipico carrier borat added
    [neopeto-pipico.kicad_pcb, neopeto-pipico.kicad_sch]
2024-11-09 cleaned silkscreen rubbish, new screenshot
    it's so annoying that the script had to add LCSC part numbers to the
    silkscreen and I didn't notice it -- exactly because it's a production
    export script and you don't expect it to modify the files you send off.
    wtf really... so annoyed
    [neopeto.kicad_pcb]
2025-01-04 fixed missing connection to VU on ch32v003
    [neopeto.kicad_pcb, neopeto.kicad_sch]
2025-01-04 layout and schematics for the docs
    [neopeto.kicad_sch]
2025-01-04 FAST_SWITCHOFF, ops order in charlieplexing
    it is important in which order the operations are performed
    FAST_SWITCHOFF (enabled) just writes zeroes to ports C and D, makes them
    inputs
    switchOn first fast-switchoffs, then sets output values and then sets up
    pin directions. This minimizes parasitic leaks, although they are still
    slightly visible.
    [cplex.h]
2025-01-08 update led resistor values
    470*2 / 20 makes for a rather dim display
    the leds are specified for 25mA at 1.6V
    100 ohm * 2 -> 17mA, bright enough not to look good next to other leds
    on my desk and on the same board
    [neopeto.kicad_pcb, neopeto.kicad_sch]
2025-01-08 pico firmware crib
    does:
    - builds (midi example that sends an arpeggio)
    - printf() to CDC stdio
    - reboots via baudrate 1200
    [main.cpp, tusb_config.h]
2025-01-11 schematic update with scopes
    [neopeto.kicad_sch]
2025-01-11 try oscilloscope in printable area
    [neopeto.kicad_sch]
2025-01-12 test notes in the schematic + debug monitor
    debug monitor provides some basic commands to test the circuit
    [neopeto.kicad_sch]
